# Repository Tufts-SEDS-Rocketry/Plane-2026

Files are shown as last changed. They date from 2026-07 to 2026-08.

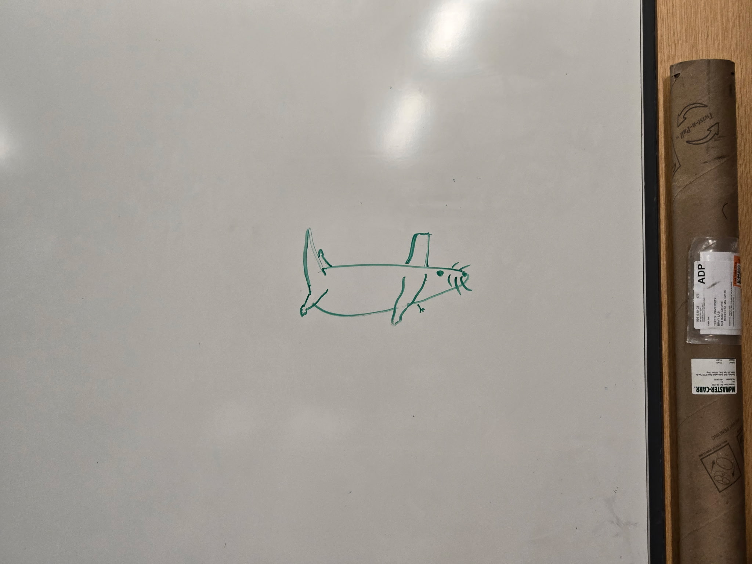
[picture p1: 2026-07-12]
img/sedsnrat.jpeg

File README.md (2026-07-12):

# SEDSna
### A plane by Tufts Rocketry

sedsnrat
ksp

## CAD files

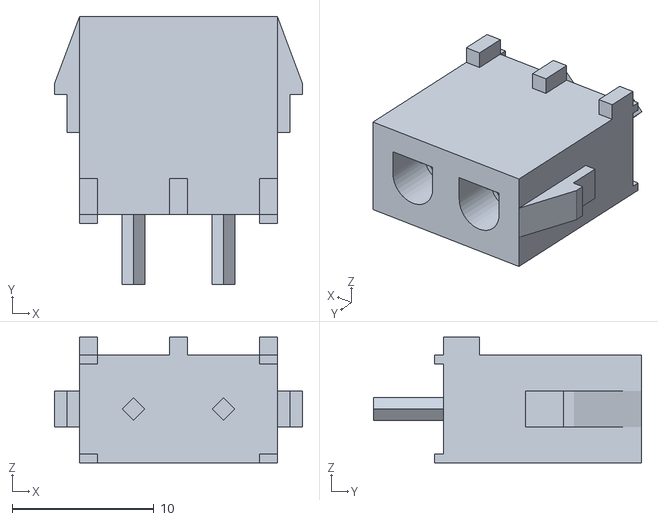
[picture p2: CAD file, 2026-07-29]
kicad/3dmodels/010845020.stl
17.5 x 18.9 x 8.89

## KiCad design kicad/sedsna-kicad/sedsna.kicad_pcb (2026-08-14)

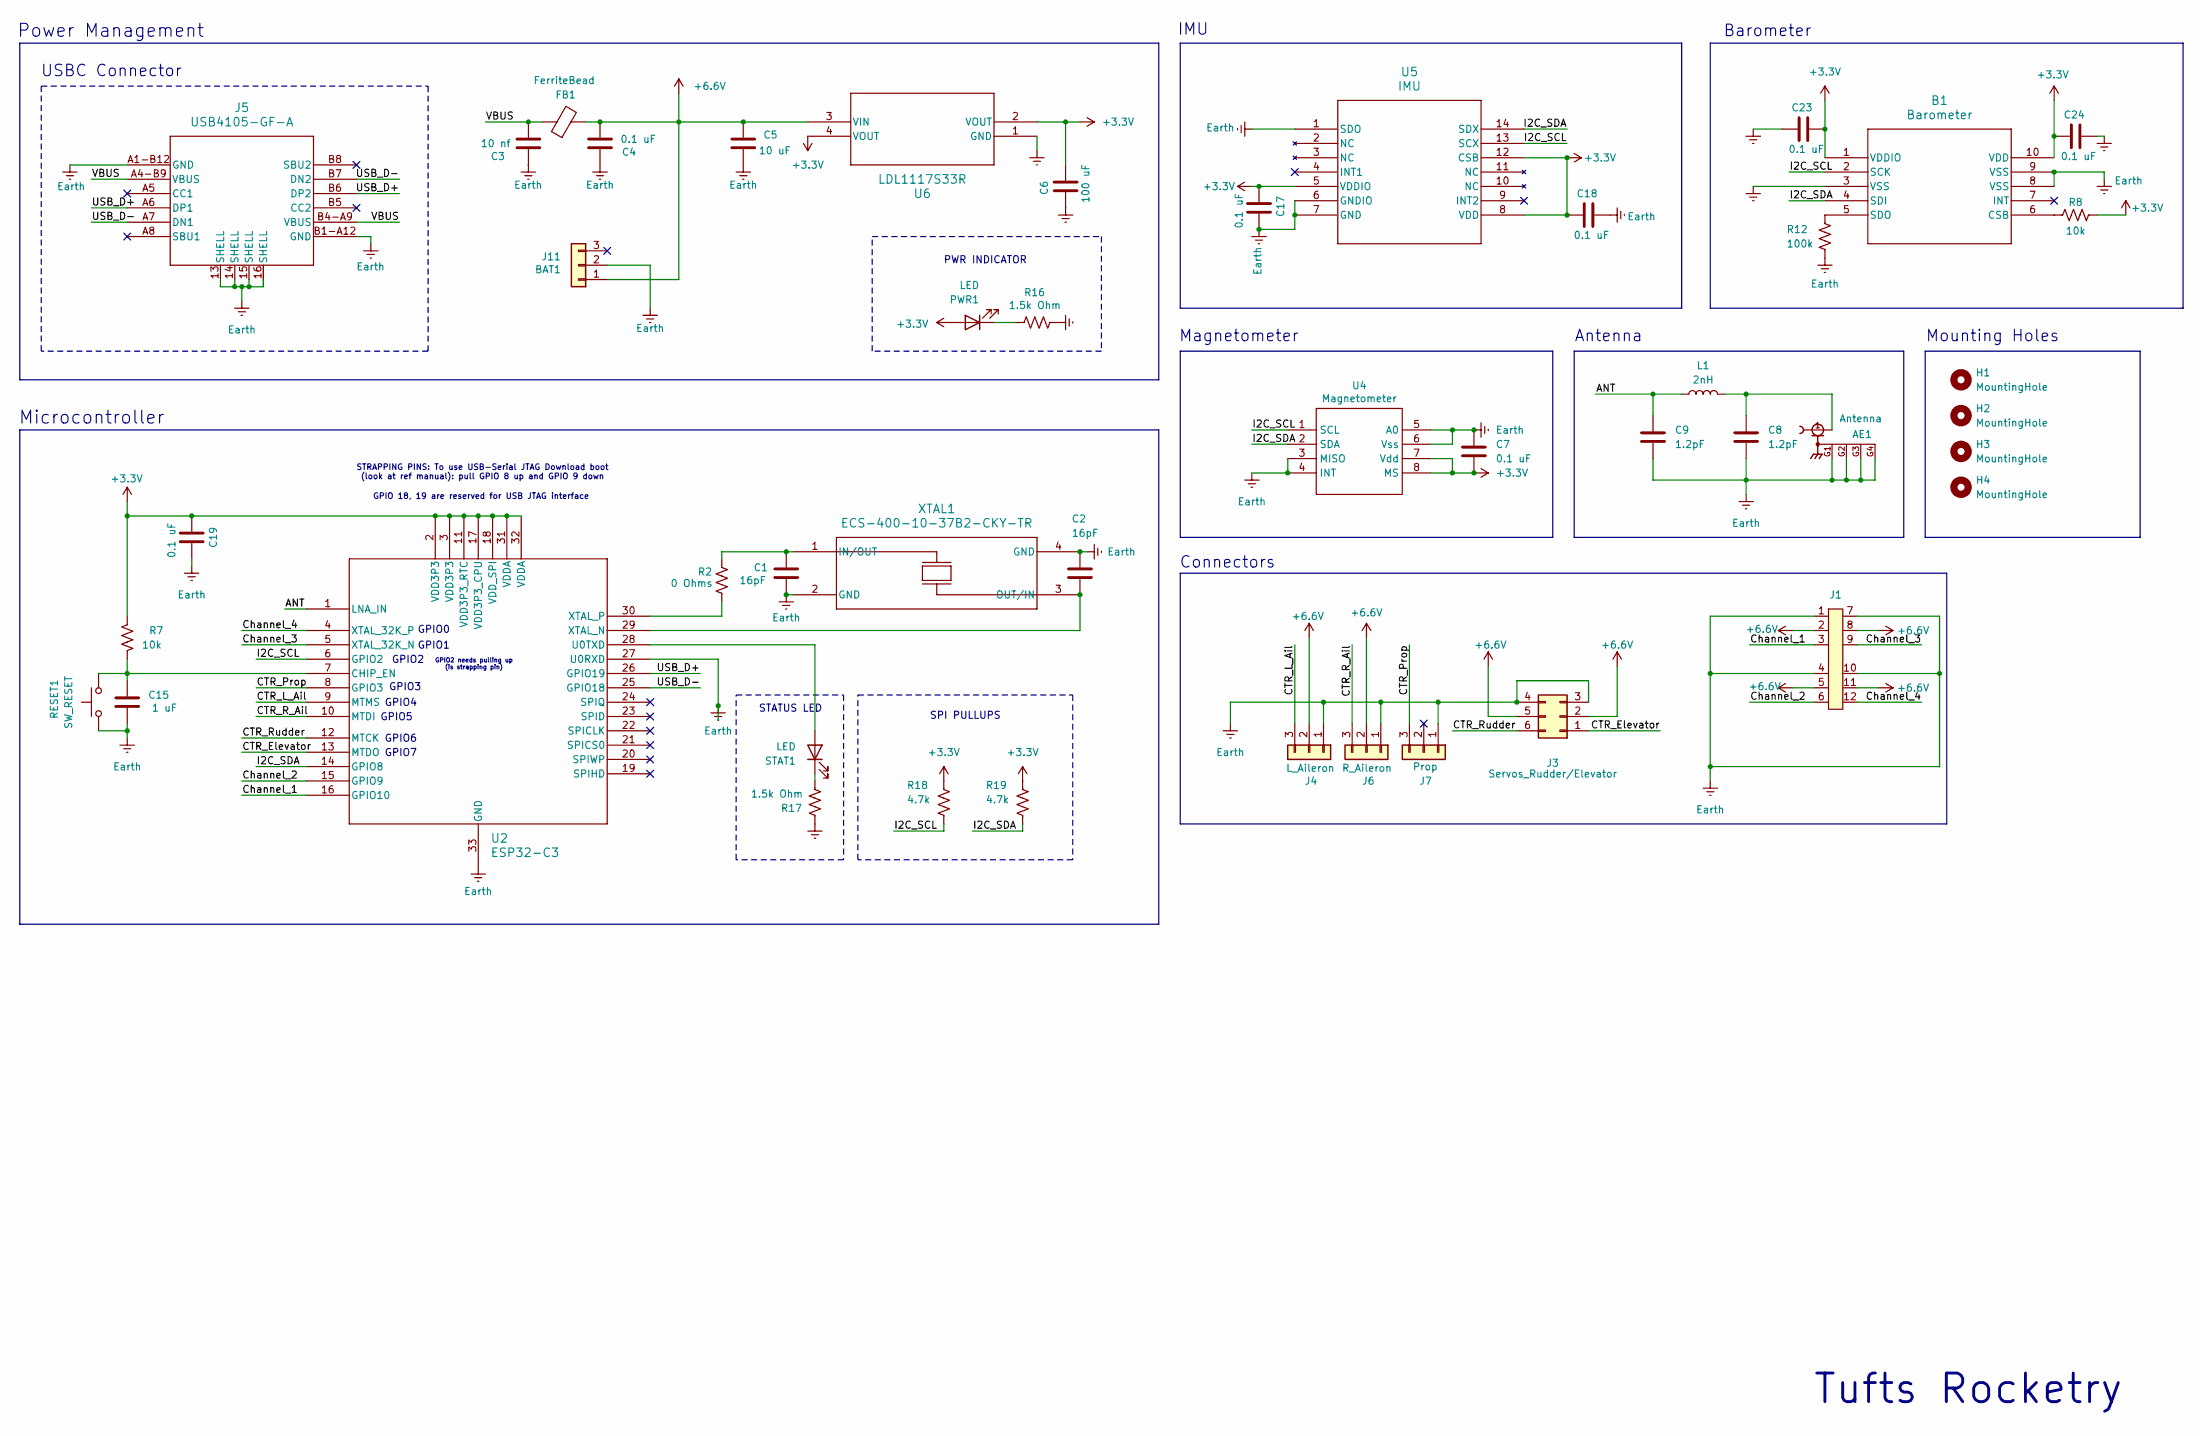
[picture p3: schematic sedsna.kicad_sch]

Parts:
AE1: Antenna; GRADCONN_RFPC-SMA28-F; PARTREV 1.0
B1: Barometer; QFN10_BMP581_BOS
C1, C2: 16pF; C_0402_1005Metric_Pad0.74x0.62mm_HandSolder
C3: 10 nf; C_0603_1608Metric
C4, C7, C17, C18, C19, C23, C24: 0.1 uF; CAP_CL05_SAM
C5: 10 uF; C_0805_2012Metric
C6: 100 uF; C_1206_3216Metric
C8, C9: 1.2pF; C_0201_0603Metric_Pad0.64x0.40mm_HandSolder
C15: 1 uF; C_0603_1608Metric
FB1: FerriteBead; FB_MI0805K400R-10
H1, H2, H3, H4: MountingHole; mounting_hole
J1: Conn_04x03
J3: Servos_Rudder/Elevator; CONN06_2035551016_MOL
J4: L_Aileron; SHDR3W166P0X635_1X3_2032X762X1397P
J5: USB4105-GF-A; USB4105_GCT
J6: R_Aileron; SHDR3W166P0X635_1X3_2032X762X1397P
J7: Prop; SHDR3W166P0X635_1X3_2032X762X1397P
J11: BAT1; SHDR3W166P0X635_1X3_2032X762X1397P
L1: 2nH; L_0402_1005Metric_Pad0.77x0.64mm_HandSolder
PWR1: LED; 150080RS75000_WRE
R2: 0 Ohms; R_0603_1608Metric_Pad0.98x0.95mm_HandSolder
R7, R8: 10k; R_0603_1608Metric_Pad0.98x0.95mm_HandSolder
R12: 100k; R_0603_1608Metric_Pad0.98x0.95mm_HandSolder
R16, R17: 1.5k Ohm; R_0603_1608Metric_Pad0.98x0.95mm_HandSolder
R18, R19: 4.7k; R_0603_1608Metric_Pad0.98x0.95mm_HandSolder
RESET1: SW_RESET; 2-pronged_THT_button
STAT1: LED; 150080RS75000_WRE
U2: ESP32-C3; QFN32_5X5_EXP
U4: Magnetometer; MAGNETO-MLX90395KDC
U5: IMU; BMI323_BOS
U6: LDL1117S33R; SOT223_STM
XTAL1: ECS-400-10-37B2-CKY-TR; XTAL_ECS-400-10-37B2-CKY-TR

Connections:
+3.3V: B1.1 (VDDIO), B1.10 (VDD), C6.2, C7.2, C17.1, C18.1, C19.1, C23.2, C24.1, PWR1.2 (A), R7.1, R8.2, R18.1, R19.1, U2.2 (VDD3P3), U2.3 (VDD3P3), U2.11 (VDD3P3_RTC), U2.17 (VDD3P3_CPU), U2.18 (VDD_SPI), U2.31 (VDDA), U2.32 (VDDA), U4.7 (Vdd), U4.8 (MS), U5.5 (VDDIO), U5.8 (VDD), U5.12 (CSB), U6.2 (VOUT), U6.4 (VOUT)
+6.6V: C4.1, C5.2, FB1.2, J1.2, J1.5, J1.8, J1.11, J3.2, J3.5, J4.2, J6.2, J11.1, U6.3 (VIN)
/ANT: C9.1, L1.1, U2.1 (LNA_IN)
/CTR_Elevator: J3.1, U2.13 (MTDO)
/CTR_L_Ail: J4.3, U2.9 (MTMS)
/CTR_Prop: J7.3, U2.8 (GPIO3)
/CTR_R_Ail: J6.3, U2.10 (MTDI)
/CTR_Rudder: J3.6, U2.12 (MTCK)
/Channel_1: J1.3, U2.16 (GPIO10)
/Channel_2: J1.6, U2.15 (GPIO9)
/Channel_3: J1.9, U2.5 (XTAL_32K_N)
/Channel_4: J1.12, U2.4 (XTAL_32K_P)
/I2C_SCL: B1.2 (SCK), R18.2, U2.6 (GPIO2), U4.1 (SCL), U5.13 (SCX)
/I2C_SDA: B1.4 (SDI), R19.2, U2.14 (GPIO8), U4.2 (SDA), U5.14 (SDX)
/USB_D+: J5.A6 (DP1), J5.B6 (DP2), U2.26 (GPIO19)
/USB_D-: J5.A7 (DN1), J5.B7 (DN2), U2.25 (GPIO18)
/VBUS: C3.1, FB1.1, J5.A4-B9 (VBUS), J5.B4-A9 (VBUS)
Earth: AE1.G1, AE1.G2, AE1.G3, AE1.G4, B1.3 (VSS), B1.8 (VSS), B1.9 (VSS), C1.2, C2.1, C3.2, C4.2, C5.1, C6.1, C7.1, C8.2, C9.2, C15.1, C17.2, C18.2, C19.2, C23.1, C24.2, J1.1, J1.4, J1.7, J1.10, J3.3, J3.4, J4.1, J5.13 (SHELL), J5.14 (SHELL), J5.15 (SHELL), J5.16 (SHELL), J5.A1-B12 (GND), J5.B1-A12 (GND), J6.1, J7.1, J11.2, R12.2, R16.2, R17.2, RESET1.1, U2.27 (U0RXD), U2.33 (GND), U4.3 (MISO), U4.4 (INT), U4.5 (A0), U4.6 (Vss), U5.1 (SDO), U5.6 (GNDIO), U5.7 (GND), U6.1 (GND), XTAL1.2 (GND), XTAL1.4 (GND)
unnamed: AE1.1, C8.1, L1.2
unnamed: B1.6 (CSB), R8.1
unnamed: B1.5 (SDO), R12.1
unnamed: PWR1.1 (K), R16.1
unnamed: STAT1.2 (A), U2.28 (U0TXD)
unnamed: R17.1, STAT1.1 (K)
unnamed: C15.2, R7.2, RESET1.2, U2.7 (CHIP_EN)
unnamed: C2.2, U2.29 (XTAL_N), XTAL1.3 (OUT/IN)
unnamed: R2.1, U2.30 (XTAL_P)
unnamed: C1.1, R2.2, XTAL1.1 (IN/OUT)

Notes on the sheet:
GPIO2
STRAPPING PINS: To use USB-Serial JTAG Download boot (look at ref manual): pull GPIO 8 up and GPIO 9 down
GPIO6
Connectors
GPIO7
Microcontroller
GPIO4
GPIO 18, 19 are reserved for USB JTAG interface
SPI PULLUPS
Tufts Rocketry
USBC Connector
GPIO1
Barometer
STATUS LED
Mounting Holes
IMU
PWR INDICATOR
Power Management
Antenna
GPIO0
GPIO3
GPIO2 needs pulling up (is strapping pin)
GPIO5
Magnetometer

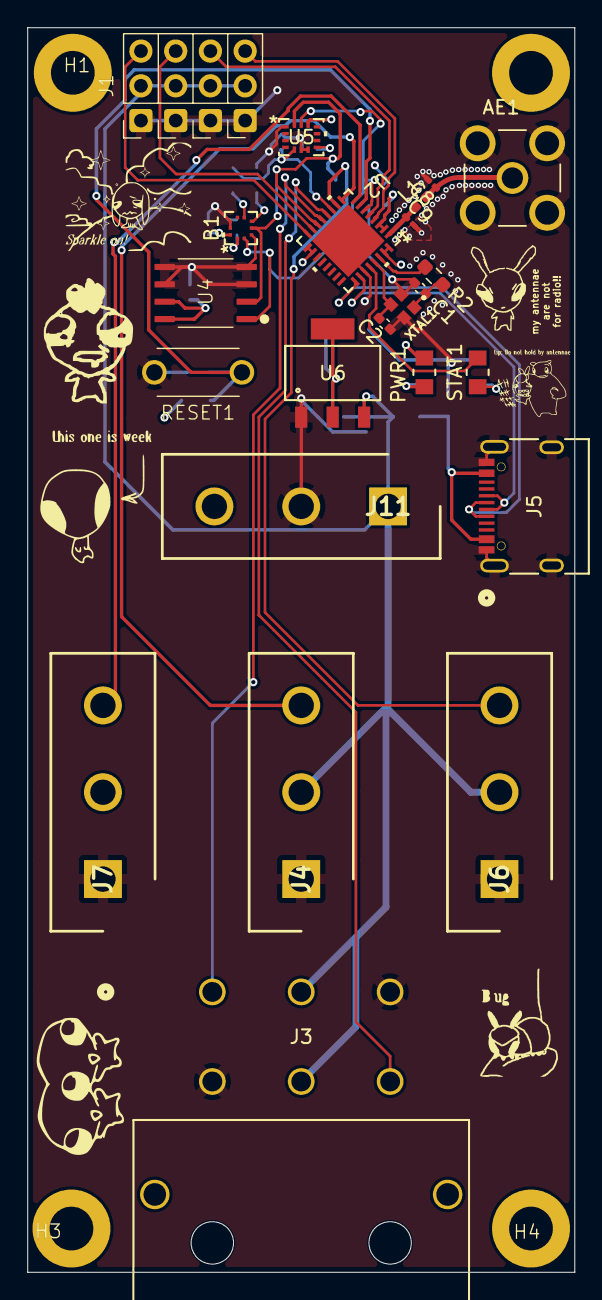
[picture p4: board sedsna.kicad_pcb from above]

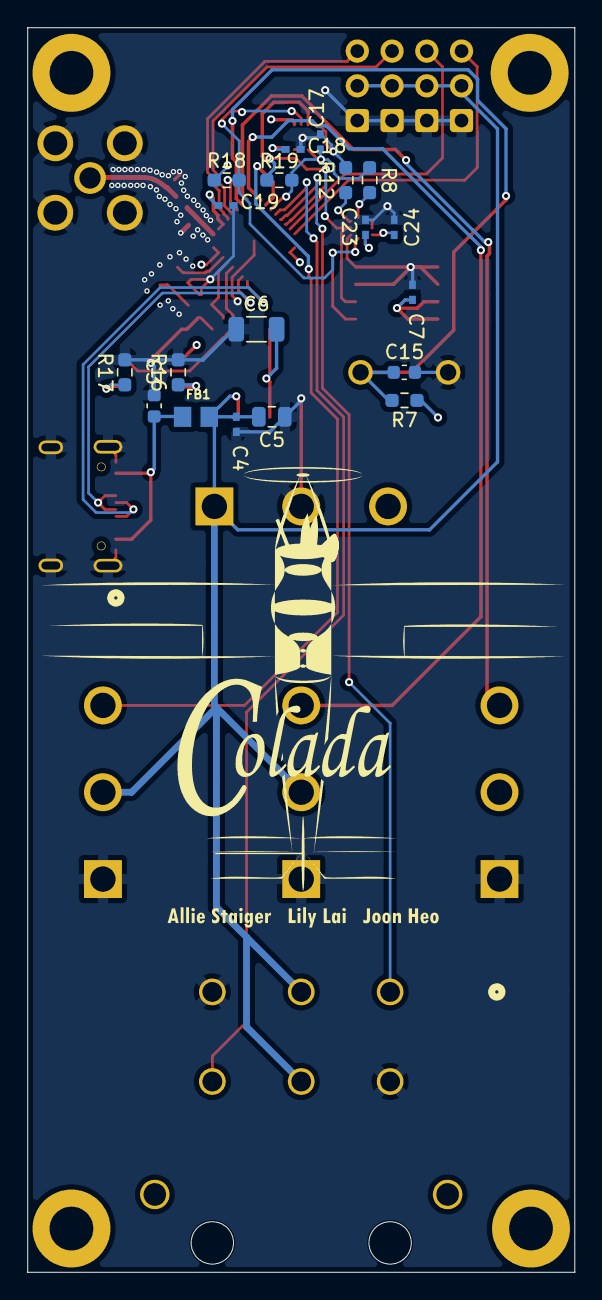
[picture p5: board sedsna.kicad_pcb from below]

Board: 4 copper layers, 40.0 x 91.0 mm, 46 parts (19 on the bottom side), 28 nets.

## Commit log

2026-07-12 kicad started
    [sedsna.kicad_pcb, sedsna.kicad_sch]
2026-07-19 Added connectors/antenna
    [sedsna.kicad_sch]
2026-07-21 (auto) (auto)
    [sedsna.PrjPcb]
2026-07-21 footprints are footprinting
    [sedsna.kicad_pcb, sedsna.kicad_sch]
2026-07-26 library shit
    aa
    [sedsna.kicad_sch]
2026-07-26 all footprints
    raaa
    [sedsna.kicad_sch]
2026-07-26 added antenna sma footprint
    142-0701-801 https://www.digikey.com/en/products/detail/cinch-connectivity-solutions-johnson/142-0701-801/35280
    [TR3_V1.SchLib, sedsna.PcbDoc, sedsna.PrjPcb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]
2026-07-28 added status led
    [sedsna.kicad_sch]
2026-07-28 pins added
    [sedsna.kicad_sch]
2026-07-29 some ERC errors fixed
    [sedsna.kicad_sch]
2026-07-29 Signal pins from receiver
    [sedsna.kicad_sch]
2026-07-29 schematic done?
    all pcb import errors cleared at least
    [010845020.stl, sedsna.kicad_pcb, sedsna.kicad_sch]
2026-08-01 pcb layout started
    [sedsna.kicad_pcb, sedsna.kicad_sch]
2026-08-01 mounting holes added
    [sedsna.kicad_pcb, sedsna.kicad_sch]
2026-08-02 Finished layout
    [sedsna.kicad_pcb, sedsna.kicad_sch]
2026-08-03 move files to kicad folder
    [010845020.stl, sedsna.kicad_pcb, sedsna.kicad_sch]
2026-08-04 did some routing
    [sedsna.kicad_pcb, sedsna.kicad_sch]
2026-08-09 PCB draft, Lily needs to do antenna stuff
    [sedsna.kicad_pcb, sedsna.kicad_sch]
2026-08-09 Logo in pcb
    [sedsna.kicad_pcb]
2026-08-11 worked on antenna trace
    worked on antenna trace :)
    [sedsna.kicad_pcb]
2026-08-14 Finished ! (?) Pretty sure!
    :)
    [sedsna.kicad_pcb]
2026-08-14 added gerbers
    [sedsna-B_Cu.gbr, sedsna-B_Mask.gbr, sedsna-B_Paste.gbr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]
